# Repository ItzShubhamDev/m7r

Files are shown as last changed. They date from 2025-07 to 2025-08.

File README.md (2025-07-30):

# M7R
A 7 Keys Macropad with a Rotary Encoder and a 0.91 inch OLED Display powered by SeeedStudio XIAO RP2040

## Features
- Utility Shortcuts
- Per Key RGB
- Multiple Layers
- OLED Display

## Bill of Materials

| Name | Footprint |  Quantity  |
|---|---|---|
| MX Switch | MX_PCB_1.00u | 7 |
| Diode | Diode_DO-35 | 8 |
|  Rotary Encoder  | Encoder_EC11_MX | 1 |
| OLED Display | OLED_128x32 | 1 |
| LED | LED_SK6812MINI | 7 |
|  XIAO RP2040 MCU |  Seeed_XIAO_RP2040  | 1 |
| PCB | - | 1 |
| Printed Case | - | 1 |

## Images

### Schematic
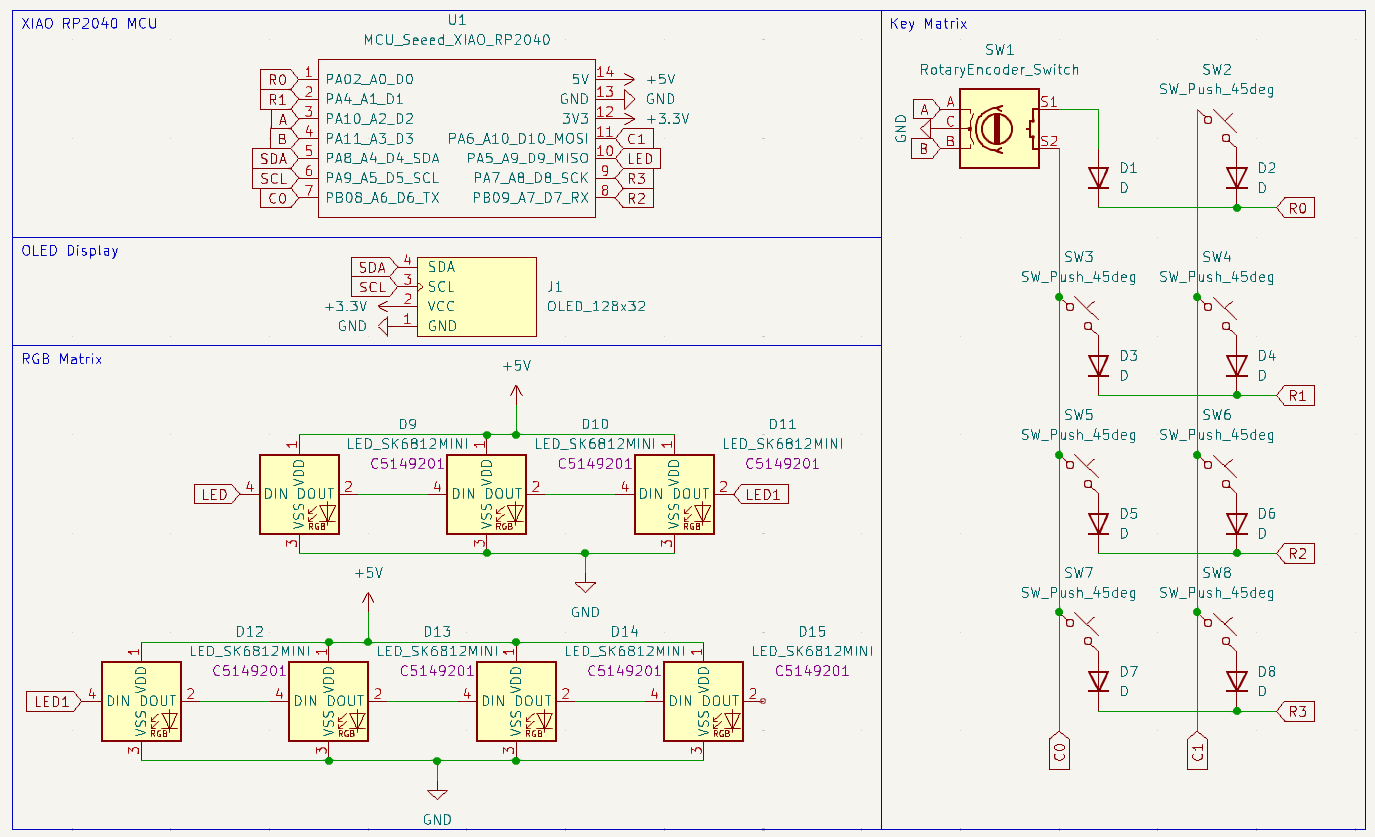
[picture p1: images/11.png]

### PCB (Front)
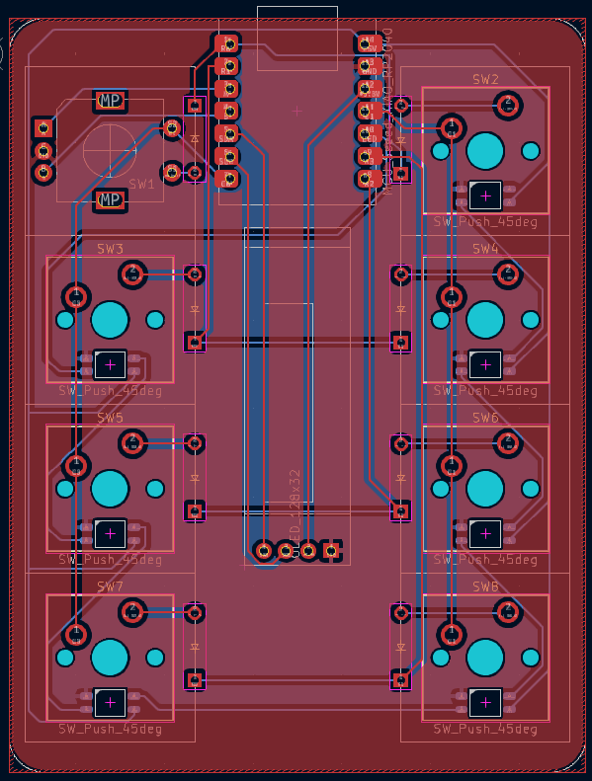
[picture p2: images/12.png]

### PCB (Back)
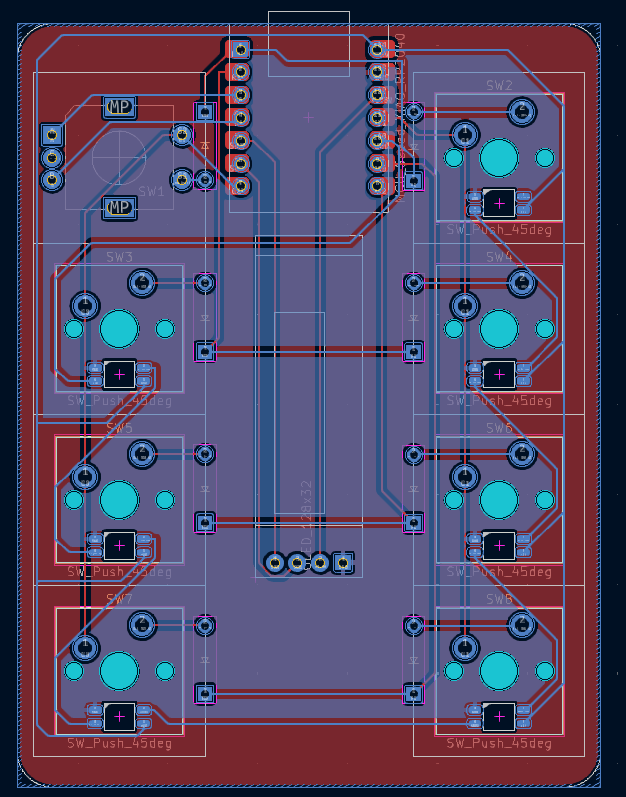
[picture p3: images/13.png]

### PCB (3D Front)
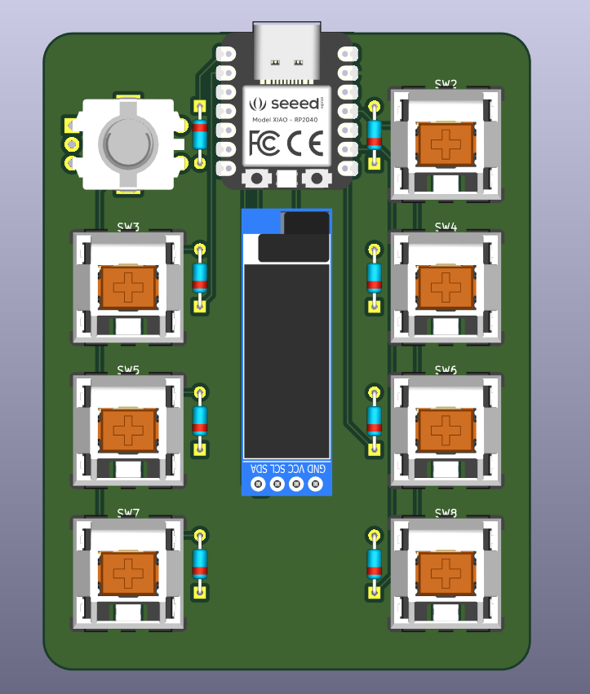
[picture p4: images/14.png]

### PCB (3D Back)
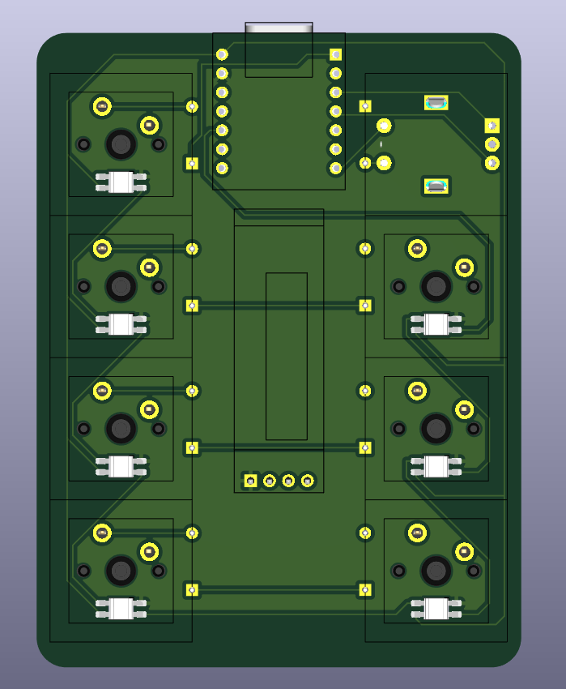
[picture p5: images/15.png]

### Case
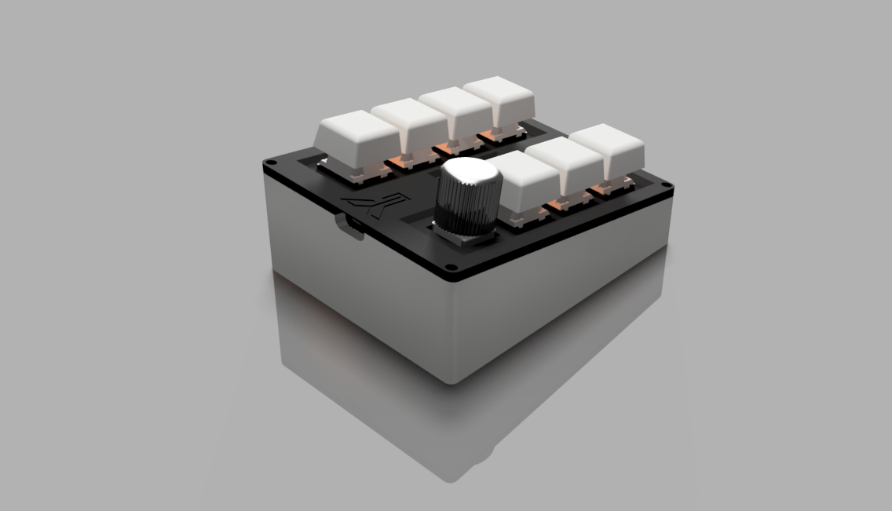
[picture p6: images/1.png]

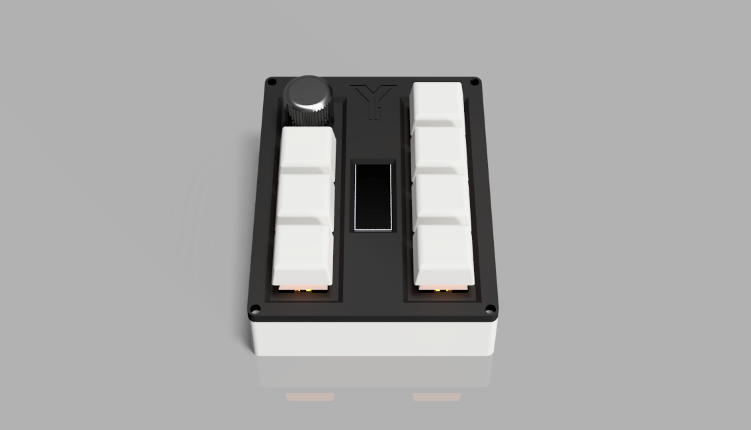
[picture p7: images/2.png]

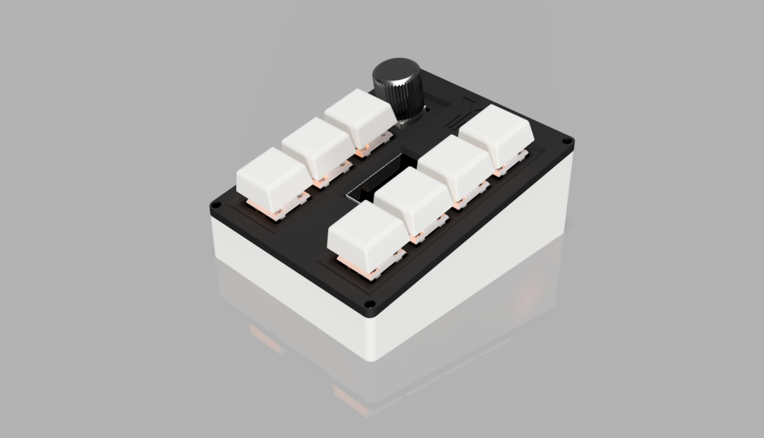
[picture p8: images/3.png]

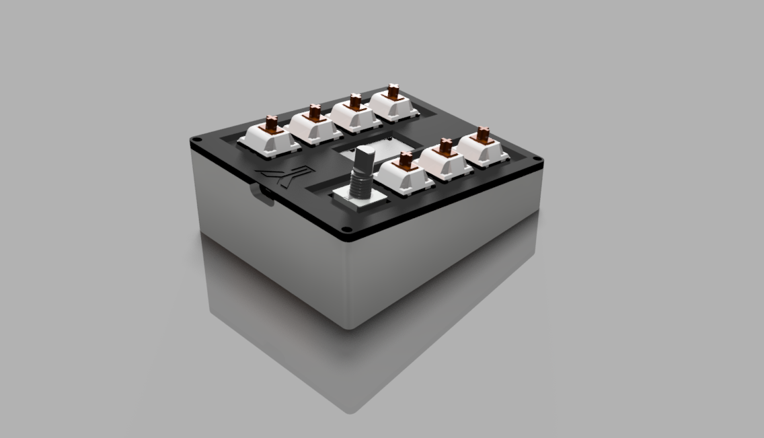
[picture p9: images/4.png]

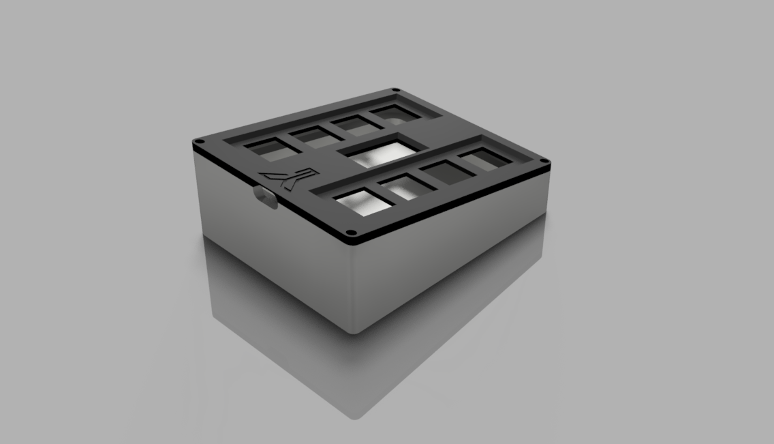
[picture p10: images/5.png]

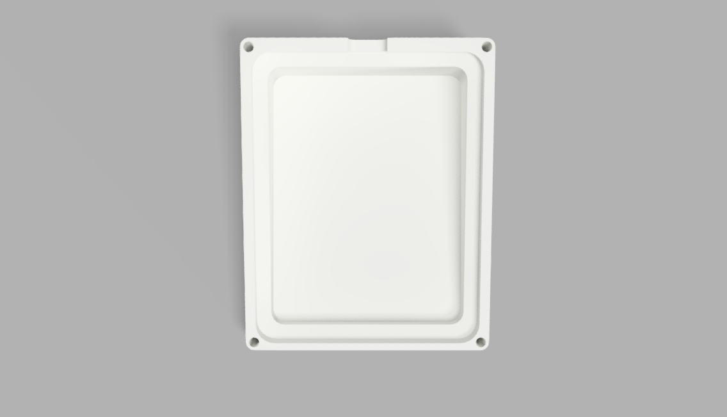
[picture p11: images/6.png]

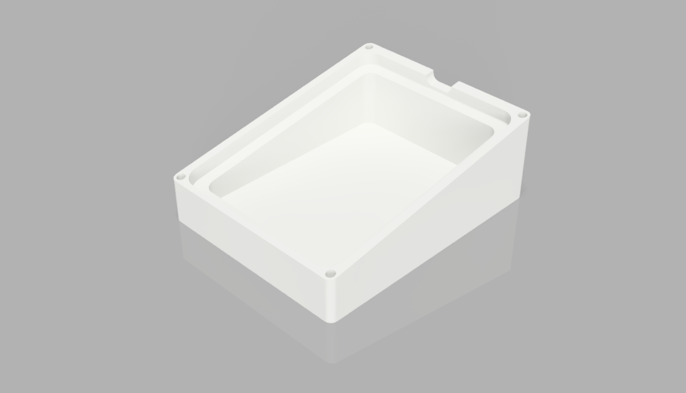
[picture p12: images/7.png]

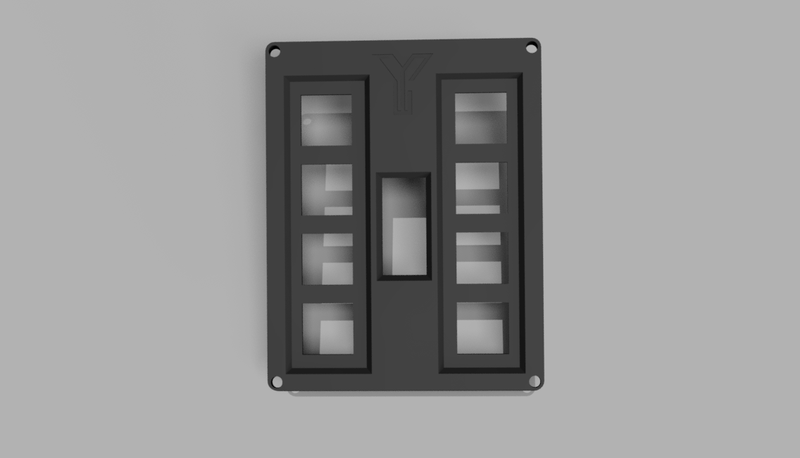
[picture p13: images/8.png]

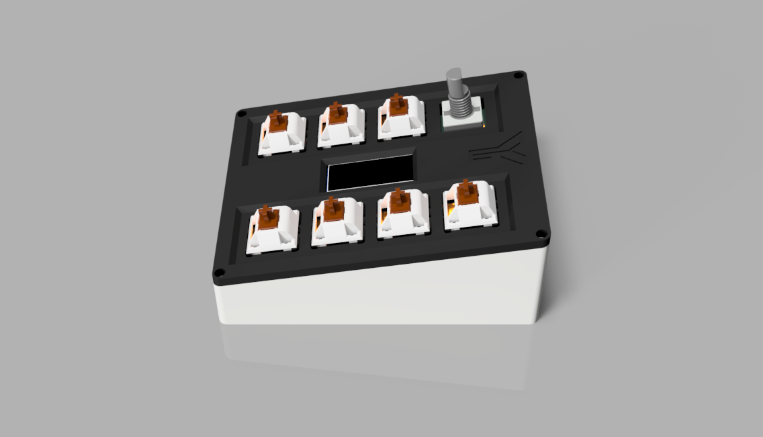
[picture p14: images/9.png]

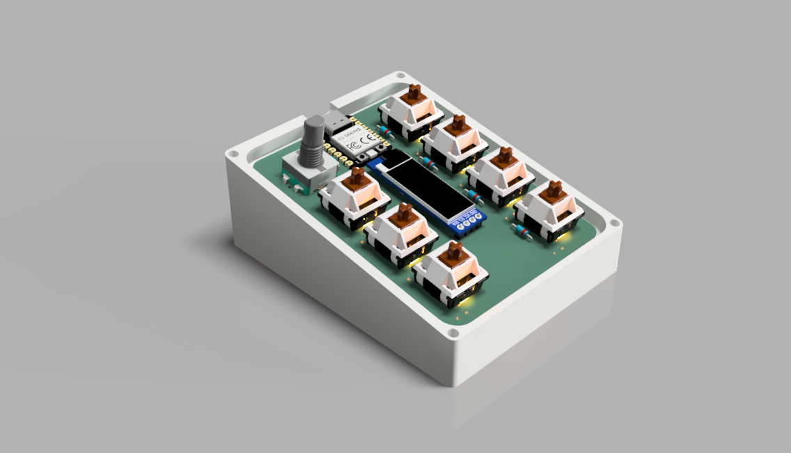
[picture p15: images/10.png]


## Additional Information

- **Firmware**: [KMK](https://github.com/KMKfw/kmk_firmware/)
- **Symbols and FootPrints**: [ScottoKicad](https://github.com/joe-scotto/scottokeebs/tree/main/Extras/ScottoKicad)
- **PCB Software**: [Kicad](https://www.kicad.org/)
- **3D Design Software**: [Autodesk Fusion 360](https://www.autodesk.com/in/products/fusion-360/overview)

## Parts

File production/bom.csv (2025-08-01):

Designator | Footprint | Quantity | Value | LCSC Part #
D1, D2, D3, D4, D5, D6, D7, D8 | Diode_DO-35 | 8 | D
D10, D11, D12, D13, D14, D15, D9 | LED_SK6812MINI | 7 | LED_SK6812MINI | C5149201
J1 | OLED_128x32 | 1 | OLED_128x32
SW1 | Encoder_EC11_MX | 1 | RotaryEncoder_Switch
SW2, SW3, SW4, SW5, SW6, SW7, SW8 | MX_PCB_1.00u | 7 | SW_Push_45deg
U1 | Seeed_XIAO_RP2040 | 1 | MCU_Seeed_XIAO_RP2040

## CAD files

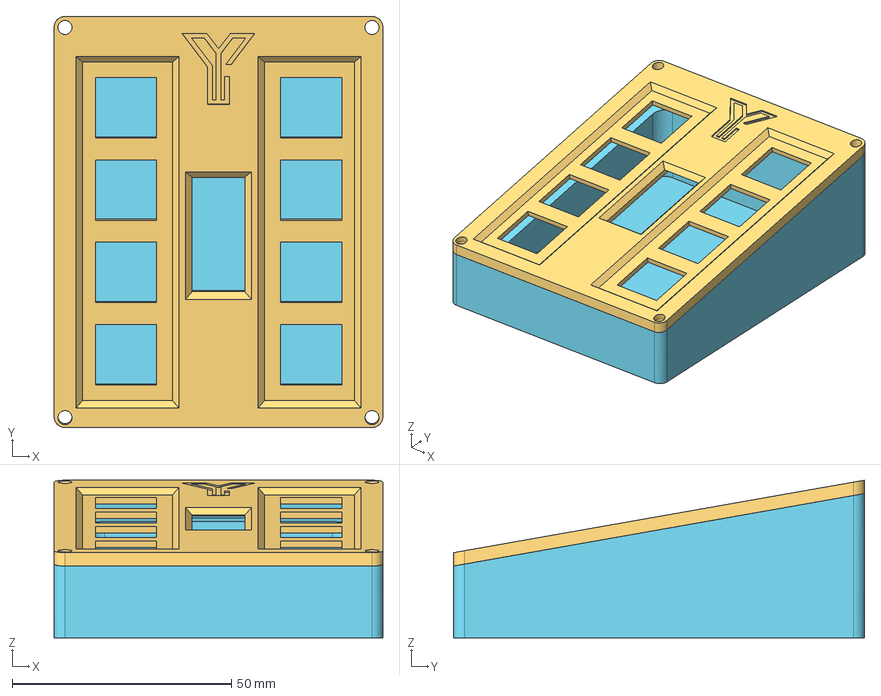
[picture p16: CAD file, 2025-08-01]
cad/Case.step
75.0 x 93.7 x 35.9 mm

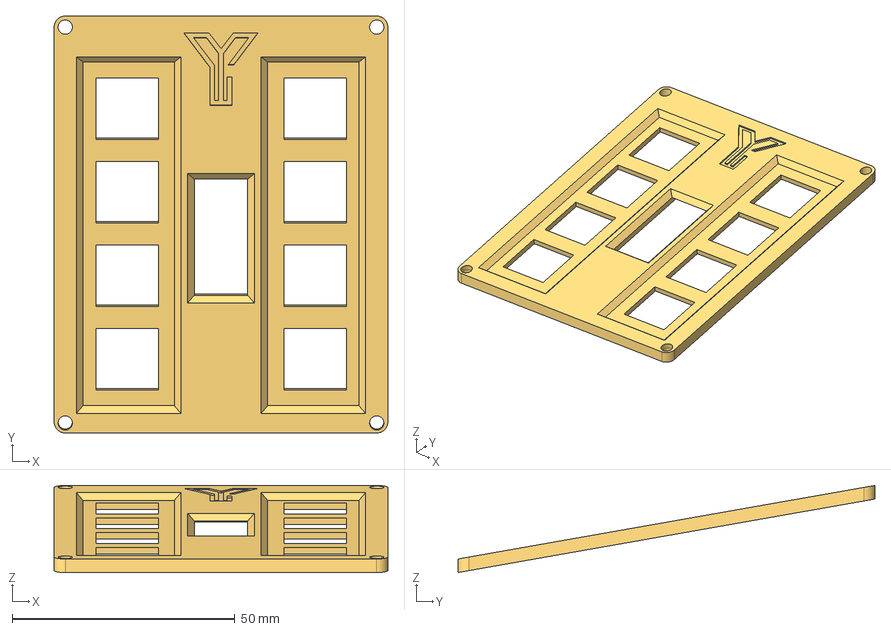
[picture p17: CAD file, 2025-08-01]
cad/Plate.step
75.0 x 93.7 x 19.6 mm

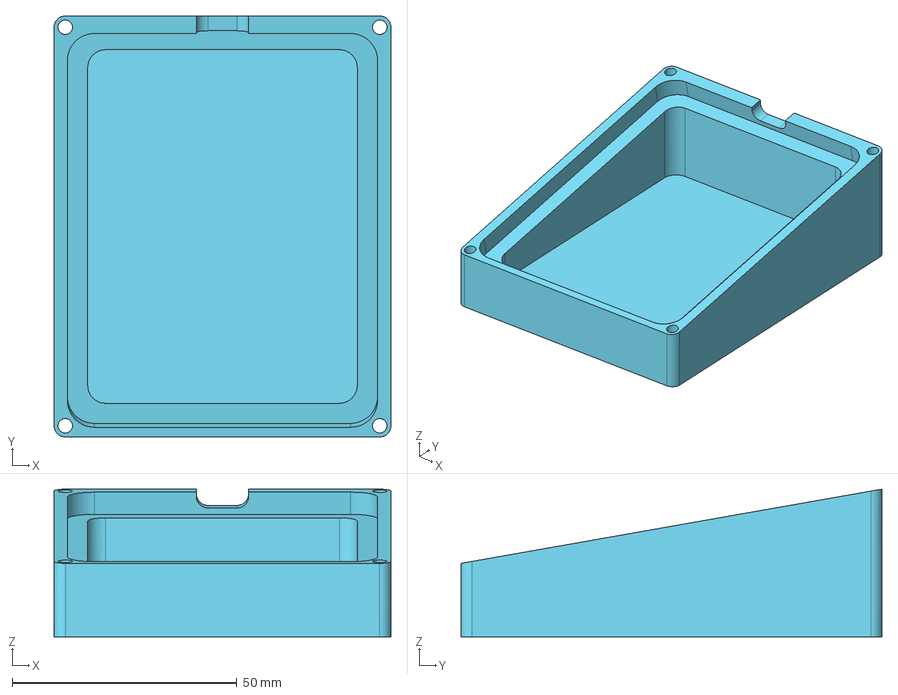
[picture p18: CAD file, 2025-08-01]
production/case/Base.step
75.0 x 93.7 x 32.9 mm

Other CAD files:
production/case/Base.stl
production/case/Case.stl
production/case/Plate.stl

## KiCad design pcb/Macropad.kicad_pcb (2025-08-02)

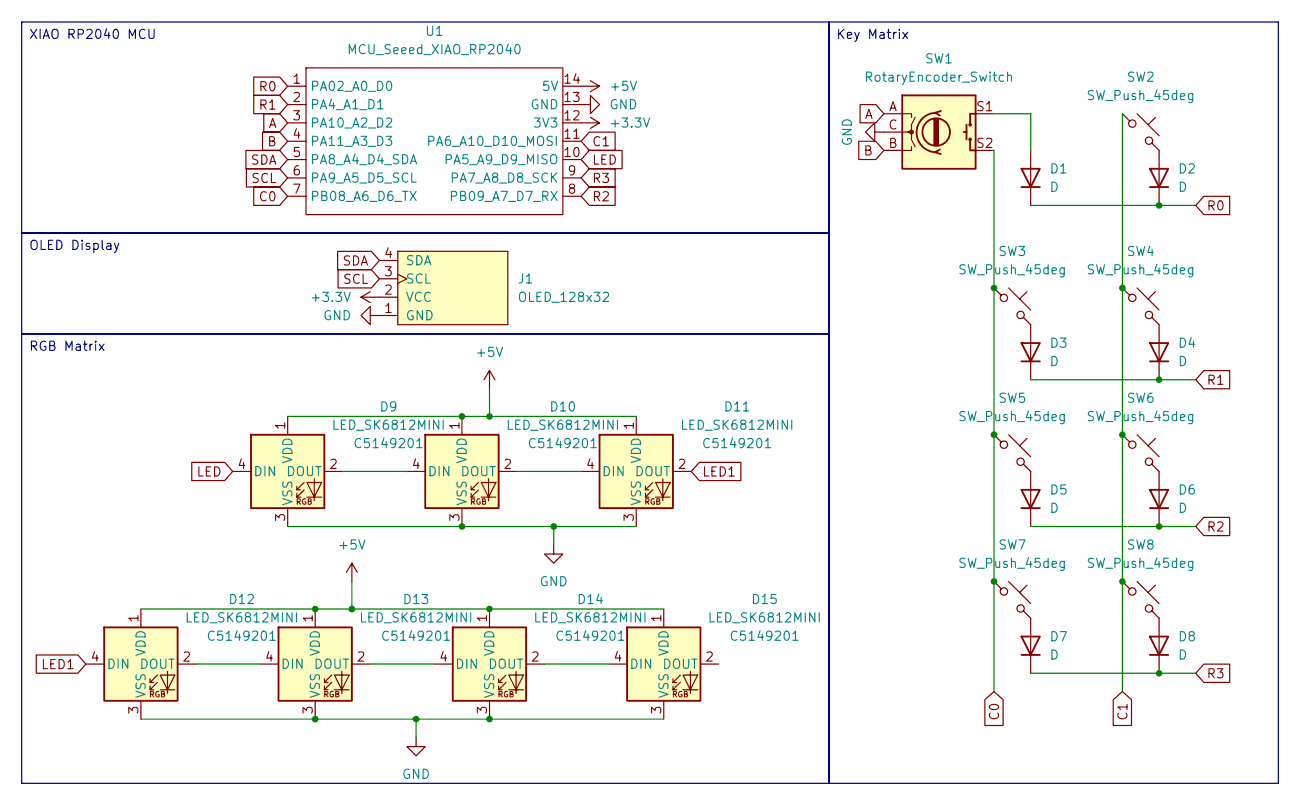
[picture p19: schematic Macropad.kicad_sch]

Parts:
D1, D2, D3, D4, D5, D6, D7, D8: D; Diode_DO-35
D9, D10, D11, D12, D13, D14, D15: LED_SK6812MINI; LCSC C5149201
J1: OLED_128x32
SW1: RotaryEncoder_Switch; Encoder_EC11_MX
SW2, SW3, SW4, SW5, SW6, SW7, SW8: SW_Push_45deg; MX_PCB_1.00u
U1: MCU_Seeed_XIAO_RP2040; Seeed_XIAO_RP2040

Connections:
+3.3V: J1.2 (VCC), U1.12 (3V3)
+5V: D9.1 (VDD), D10.1 (VDD), D11.1 (VDD), D12.1 (VDD), D13.1 (VDD), D14.1 (VDD), D15.1 (VDD), U1.14 (5V)
A: SW1.A, U1.3 (PA10_A2_D2)
B: SW1.B, U1.4 (PA11_A3_D3)
C0: SW1.S2, SW3.1, SW5.1, SW7.1, U1.7 (PB08_A6_D6_TX)
C1: SW2.1, SW4.1, SW6.1, SW8.1, U1.11 (PA6_A10_D10_MOSI)
GND: D9.3 (VSS), D10.3 (VSS), D11.3 (VSS), D12.3 (VSS), D13.3 (VSS), D14.3 (VSS), D15.3 (VSS), J1.1 (GND), SW1.C, U1.13 (GND)
LED: D9.4 (DIN), U1.10 (PA5_A9_D9_MISO)
LED1: D11.2 (DOUT), D12.4 (DIN)
unnamed: D1.2 (A), SW1.S1
unnamed: D2.2 (A), SW2.2
unnamed: D3.2 (A), SW3.2
unnamed: D4.2 (A), SW4.2
unnamed: D5.2 (A), SW5.2
unnamed: D6.2 (A), SW6.2
unnamed: D7.2 (A), SW7.2
unnamed: D8.2 (A), SW8.2
unnamed: D9.2 (DOUT), D10.4 (DIN)
unnamed: D10.2 (DOUT), D11.4 (DIN)
unnamed: D12.2 (DOUT), D13.4 (DIN)
unnamed: D13.2 (DOUT), D14.4 (DIN)
unnamed: D14.2 (DOUT), D15.4 (DIN)
R0: D1.1 (K), D2.1 (K), U1.1 (PA02_A0_D0)
R1: D3.1 (K), D4.1 (K), U1.2 (PA4_A1_D1)
R2: D5.1 (K), D6.1 (K), U1.8 (PB09_A7_D7_RX)
R3: D7.1 (K), D8.1 (K), U1.9 (PA7_A8_D8_SCK)
SCL: J1.3 (SCL), U1.6 (PA9_A5_D5_SCL)
SDA: J1.4 (SDA), U1.5 (PA8_A4_D4_SDA)

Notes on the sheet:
OLED Display
XIAO RP2040 MCU
RGB Matrix
Key Matrix

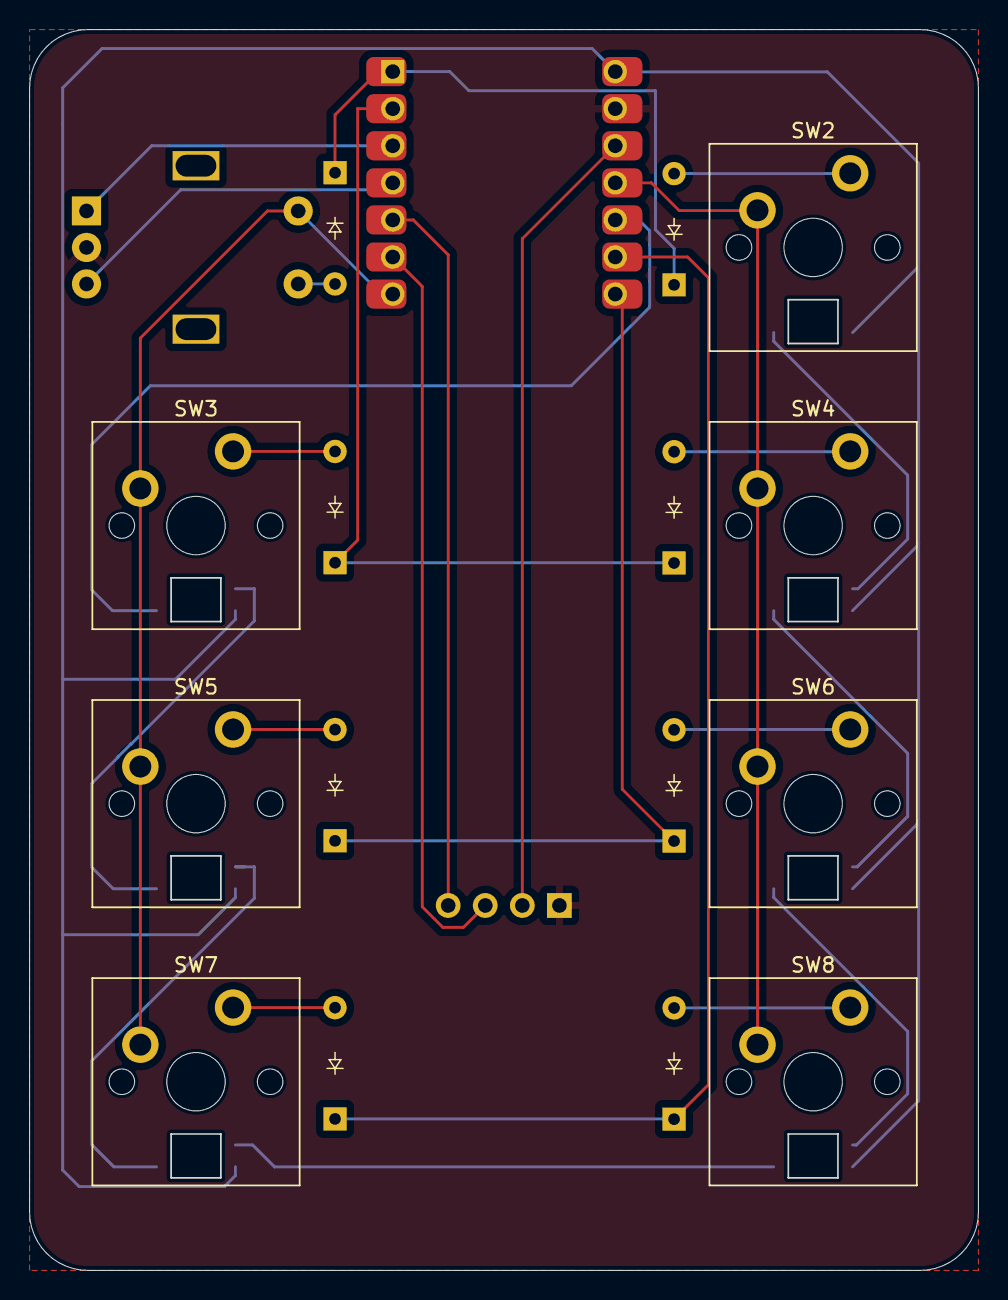
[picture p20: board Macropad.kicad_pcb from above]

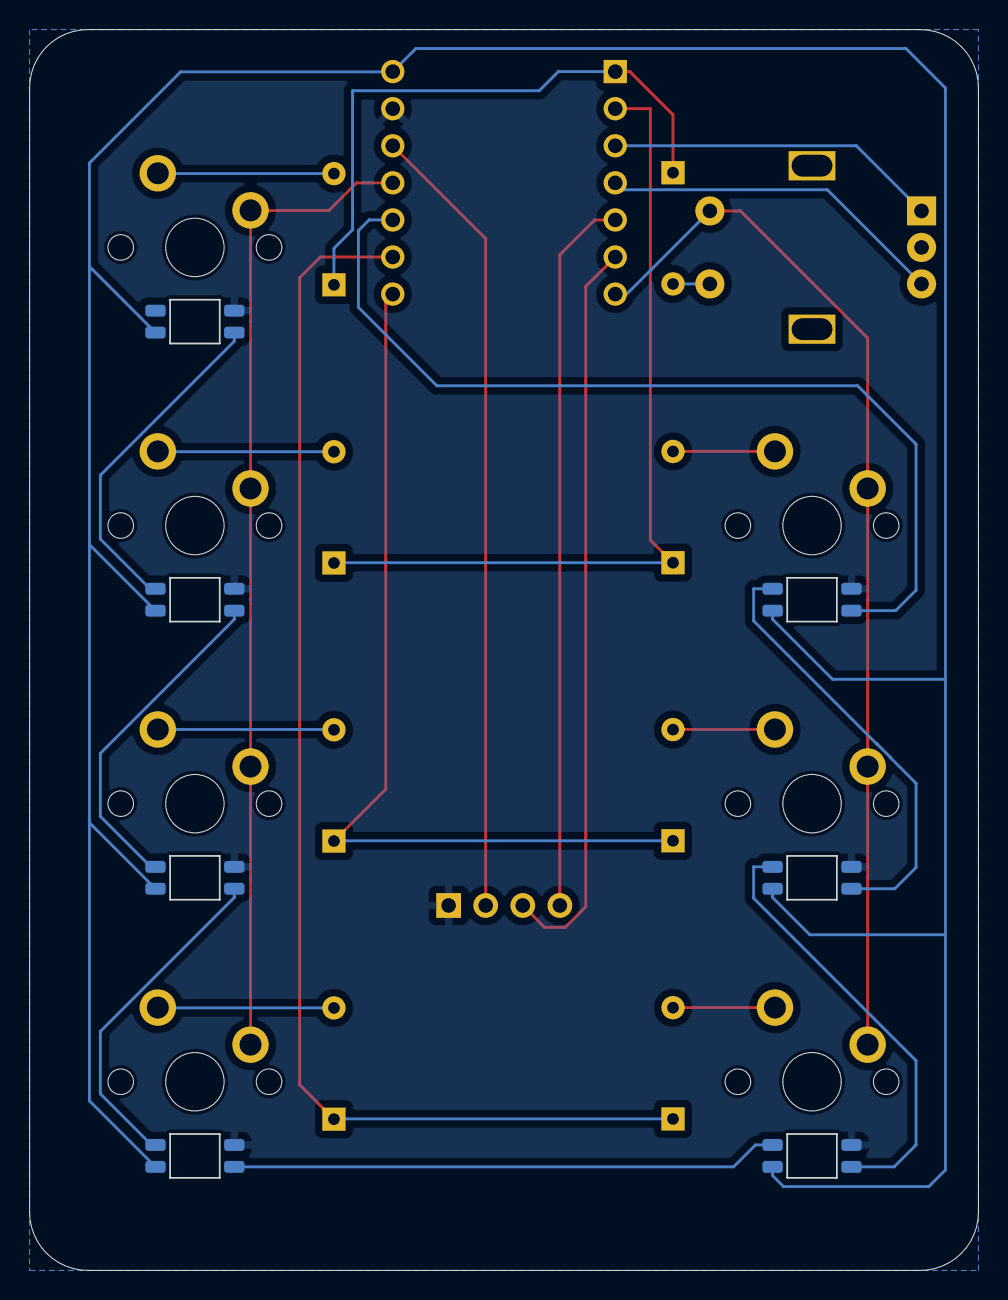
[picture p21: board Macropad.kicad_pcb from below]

Board: 2 copper layers, 65.0 x 85.0 mm, 25 parts (7 on the bottom side), 28 nets.

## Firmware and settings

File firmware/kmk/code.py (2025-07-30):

import board
import busio
from adafruit_ssd1306 import SSD1306_I2C

from kmk.kmk_keyboard import KMKKeyboard
from kmk.keys import KC
from kmk.scanners.keypad import KeysScanner
from kmk.scanners import DiodeOrientation

from kmk.modules.layers import Layers
from kmk.modules.macros import Press, Release, Tap, Macros
from kmk.modules.encoder import EncoderHandler

from kmk.extensions.rgb import RGB

keyboard = KMKKeyboard()
i2c = busio.I2C(board.SCL, board.SDA)

macros = Macros()
encoder_handler = EncoderHandler()

keyboard.modules.append(encoder_handler)
keyboard.modules.append(macros)
keyboard.modules.append(Layers())

keyboard.col_pins = (board.D7, board.D11)
keyboard.row_pins = (board.D0, board.D1, board.D8, board.D9)
keyboard.diode_orientation = DiodeOrientation.COL2ROW

encoder_handler.pins = ((board.D2, board.D3, None))

rgb = RGB(pixel_pin=board.D10, num_pixels=7)
keyboard.extensions.append(rgb)

class Display(SSD1306_I2C):
    def on_layer_change(self, layer: int):
        self.fill(0)
        self.text(f'M7R - {layer}', 0, 0, 1)
        self.show()

display = Display(128, 32, i2c)  
keyboard.extensions.append(display)  

keyboard.keymap = [
  [
    KC.MUTE, KC.Macro(Press(KC.LCTRL), Tap(KC.C), Release(KC.LCTRL)),
    KC.Macro(Press(KC.LCTRL), Tap(KC.X), Release(KC.LCTRL)), KC.Macro(Press(KC.LCTRL), Tap(KC.V), Release(KC.LCTRL)),
    KC.Macro(Press(KC.LALT), Press(KC.LSHIFT), Tap(KC.F), Release(KC.LSHIFT), Release(KC.LALT)), KC.Macro(Press(KC.LGUI), Tap(KC.PSCREEN), Release(KC.LGUI)),
    KC.MO(1), KC.LT(2, KC.RGB_TOG)
  ],
  [
    KC.MUTE, KC.MACRO(Press(KC.LCTRL), Tap(KC.A), Release(KC.LCTRL)),
    KC.MACRO(Press(KC.LCTRL), Tap(KC.S), Release(KC.LCTRL)), KC.Macro(Press(KC.LALT), Tap(KC.Tab), Release(KC.LALT)), 
    KC.Macro(Press(KC.LGUI), Press(KC.LSHIFT), Tap(KC.S), Release(KC.LSHIFT), Release(KC.LGUI)), KC.MEDIA_PREV_TRACK,
    KC.MEDIA_PLAY_PAUSE, KC.MEDIA_NEXT_TRACK,
  ],
  [
    KC.KC.RGB_MODE_PLAIN, KC.RGB_MODE_BREATHE,
    KC.RGB_MODE_RAINBOW, KC.RGB_MODE_KNIGHT,
    KC.RGB_MODE_BREATHE_RAINBOW, KC.RGB_MODE_SWIRL,
    KC.RGB_SAI, KC.RGB_SAD,
  ]
]

encoder_handler.map = [
  [
    KC.VOLU, KC.VOLD
  ],
  [
    KC.VOLU, KC.VOLD
  ],
  [
    KC.RGB_HUI, KC.RGB_HUD
  ]
]

display.fill(0)
display.text('M7R', 0, 0, 1)
display.show()

if __name__ == '__main__':
    keyboard.go()

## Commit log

2025-08-01 Reorganise files
    [Base.step, Base.stl, Case.step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]
2025-08-02 Fix Rotary Encoder
    [Macropad.kicad_pcb, Macropad.kicad_sch]
